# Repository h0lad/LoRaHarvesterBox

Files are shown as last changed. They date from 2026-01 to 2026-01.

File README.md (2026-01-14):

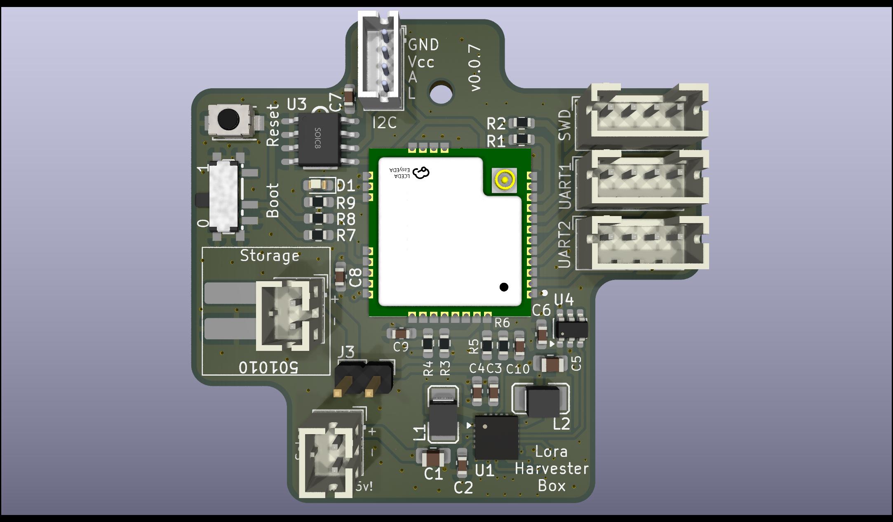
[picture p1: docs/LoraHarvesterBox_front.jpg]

MeshtasticRouterNode

## What is this thing?

This generic LoRa base board is built around the ST STM32WLE5CC (RAK3172) and the TI BQ25570 energy harvester.

It is suitable for a wide range of applications, including:

- Meshtastic (router, sensor) or Meshcore
- LoRaWAN sensors
- Generic raw LoRa devices
- Or virtually any other custom project (ham balloon? Transmitter for tracking penguins?) that utilizes the modulation schemes (FSK, GFSK, MSK, GMSK) of the SX1262

For persistent data storage, an optional FRAM IC (Infineon FM24V10) can be added using I²C. A variety of sensors can additonaly integrated through I²C, SPI (on the back), or USART interfaces.

The power supply design is highly flexible: alongside standard JST-PH connectors, the board also supports very small LiPo batteries (commonly used in in-ear headphones or Bluetooth headsets), which can be soldered directly. Such batteries are readily available on AliExpress (e.g. 501010). The TI BQ25570 also supports exotic storages like Supercaps, LTO, etc.

## Features

### Energy

- Capable of handling a huge variety of energy storages: LiPo, LiFePo4, LTO, SIB, Supercap
- Starts boosting at 600mV. Maximum input voltage is 5.5V. 
- Up to 110mA can be used from the application
- MPPT
- Optional load-switch to switch on/off the entire STM32/LoRa-modem based on the VBAT_OK signal

### Microcontroller

Uses the standardized RAK housing which can house a variety of platforms (ESP32, STM32, etc.) with compatible pins. This variant uses the RAK3172  (ST STM32WLE5CC: 256Kb Flash, 64Kb RAM, 48MHz).

Exposed interfaces:

- 2x USART
- 1x I2C
- 1x SPI (back)
- 2x ADC connected to energy source (like solar) and and energy storage (like LiPos) using voltage dividers
- Multiple break-out pins for GPIOs on the back

### LoRa

Uses the Semtech SX1262 integrated within the STM32 housing. Multiple RAK variants available for 433/470/868/915MHz.

### Data Storage

Infineon FM24V10: 1-MBit non-volatile F-RAM for storing firmware updates, messages or mesurement data

## Physical Dimensions

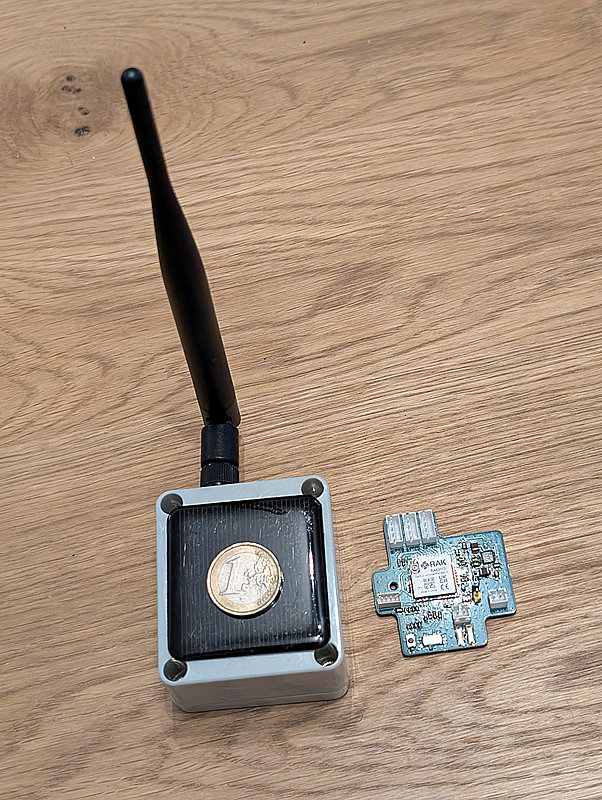
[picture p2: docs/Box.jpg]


This weirdo PCB format is designed around the cheapest water protected box from Aliexpress.

[Aliexpress, F-type, 63x58x35](https://de.aliexpress.com/item/1005005480970197.html)

## Design Decisions

### Why did you use the TI BQ25570?

It's the only energy harvester that supports up to 110mA peak current.

I'm not overly happy with this IC as it lacks a few useful features:

 - No I²C interface and ADC for reading voltages/currents

 - No Thermistor for switching off charging above and below specific temperatures

 - Doesn't switch off VOUT if the battery hits the lower threshold. It only signals it using a pin.

 - Rather annoying pin configuration. Layouting it doesn't make much fun.

 - It doesn't have interal high-precision resistors for configuring the voltage limits (VBAT_OV, etc.). Even with 1% tolerance resistors the resulting voltage ranges are barely acceptable due to error propagation.

 - Lowest possible battery voltage is 1.9V. This means we cannot utilize the full capacity of "exotic" storage types like LTO- and NaIon-cells.

Honestly - It's an old thing compared to the latest generation from ST or e-peas.
  
### Why not buying a "naked" ST STM32WLE5? 

Using a SoC module from RAK brings all the HF and impedancy matching. 

Everything else leaving the housing is not really critical signal wise.

Also it's not too expensive with 6€.

## Hardware

### Pin Configuration

MeshtasticRouterNode

#### ADC

| Signal | Pin | ADC Channel | Info | 
|:---:|:----:|:---:|:---:|
| Energy Storage Voltage | PB3 | A0 | Voltage goes through a Voltage Divider |
| Energy Source Voltage  | PB4 | A1 | Voltage goes through a Voltage Divider |

#### USART

| Peripheral | TX Pin | RX Pin |
|:---|:---|:---|
| UART1 | PB6 | PB7 |
| UART2 | PA2 | PA3 |

#### SWD

| Signal | Pin |
|:---|:----|
| SWDIO | PA13 |
| SWCLK | PA14 |

##### SPI

| Signal | Pin |
|:---|:----|
| SPI1, MOSI | PA7 |
| SPI1, MISO | PA6 |
| SPI1, CLK  | PA5 |
| SPI1, NSS  | PA4 |

#### LED

| Signal | Pin |
|:---|:----|
| LED | PA8 |

#### MISC

| Signal | Pin |
|:---|:----|
| VBAT_OK from TI BQ25570| PA15 |

### Resistors Values

**Warning:** 

You have to be super careful here. Don't trust your 1%-SMD-Resistor book from Aliexpress or Amazon. Measure each resistor with a high-resolution multimeter and then calculate the voltages according to the readings! A shabby Libreoffice Calc sheet can be found within the `docs` folder to do this.

I wrote a script for calculating resistor values here: [ti-bq25570-calculator](https://github.com/h0lad/ti-bq25570-calculator).

## Hardware Verification

### PCB Version v0.0.5

LoRaHarvesterBox PCB v0.0.5

**Power Chain**

✅ 3.3V from TI BQ25570

✅ Charges power storage as defined with R_OV1 and R_OV2

✅ VBAT_OK signal with 3.3V LiPo attached as a storage

✅ Boosts 0.6V to 3.3V without energy storage attached

✅ Lower and upper  VBAT_OK threshold

✅ Power switch (TI TPS22917DBV)

**ST STM32WL55**

✅ Connect to the SWD interface using a ST-Link

**Findings**

1. The BQ25570 doesn't like my extremely noisy power supply as a storage emulation. It doesn't come up.

2. You have to be very careful as even the tolerance of 1% resistors (R_OV1 and R_OV2) might cause overcharging. So stay away from the hard limits of your battery.

## License

CERN Open Hardware Licence Version 2 - Strongly Reciprocal

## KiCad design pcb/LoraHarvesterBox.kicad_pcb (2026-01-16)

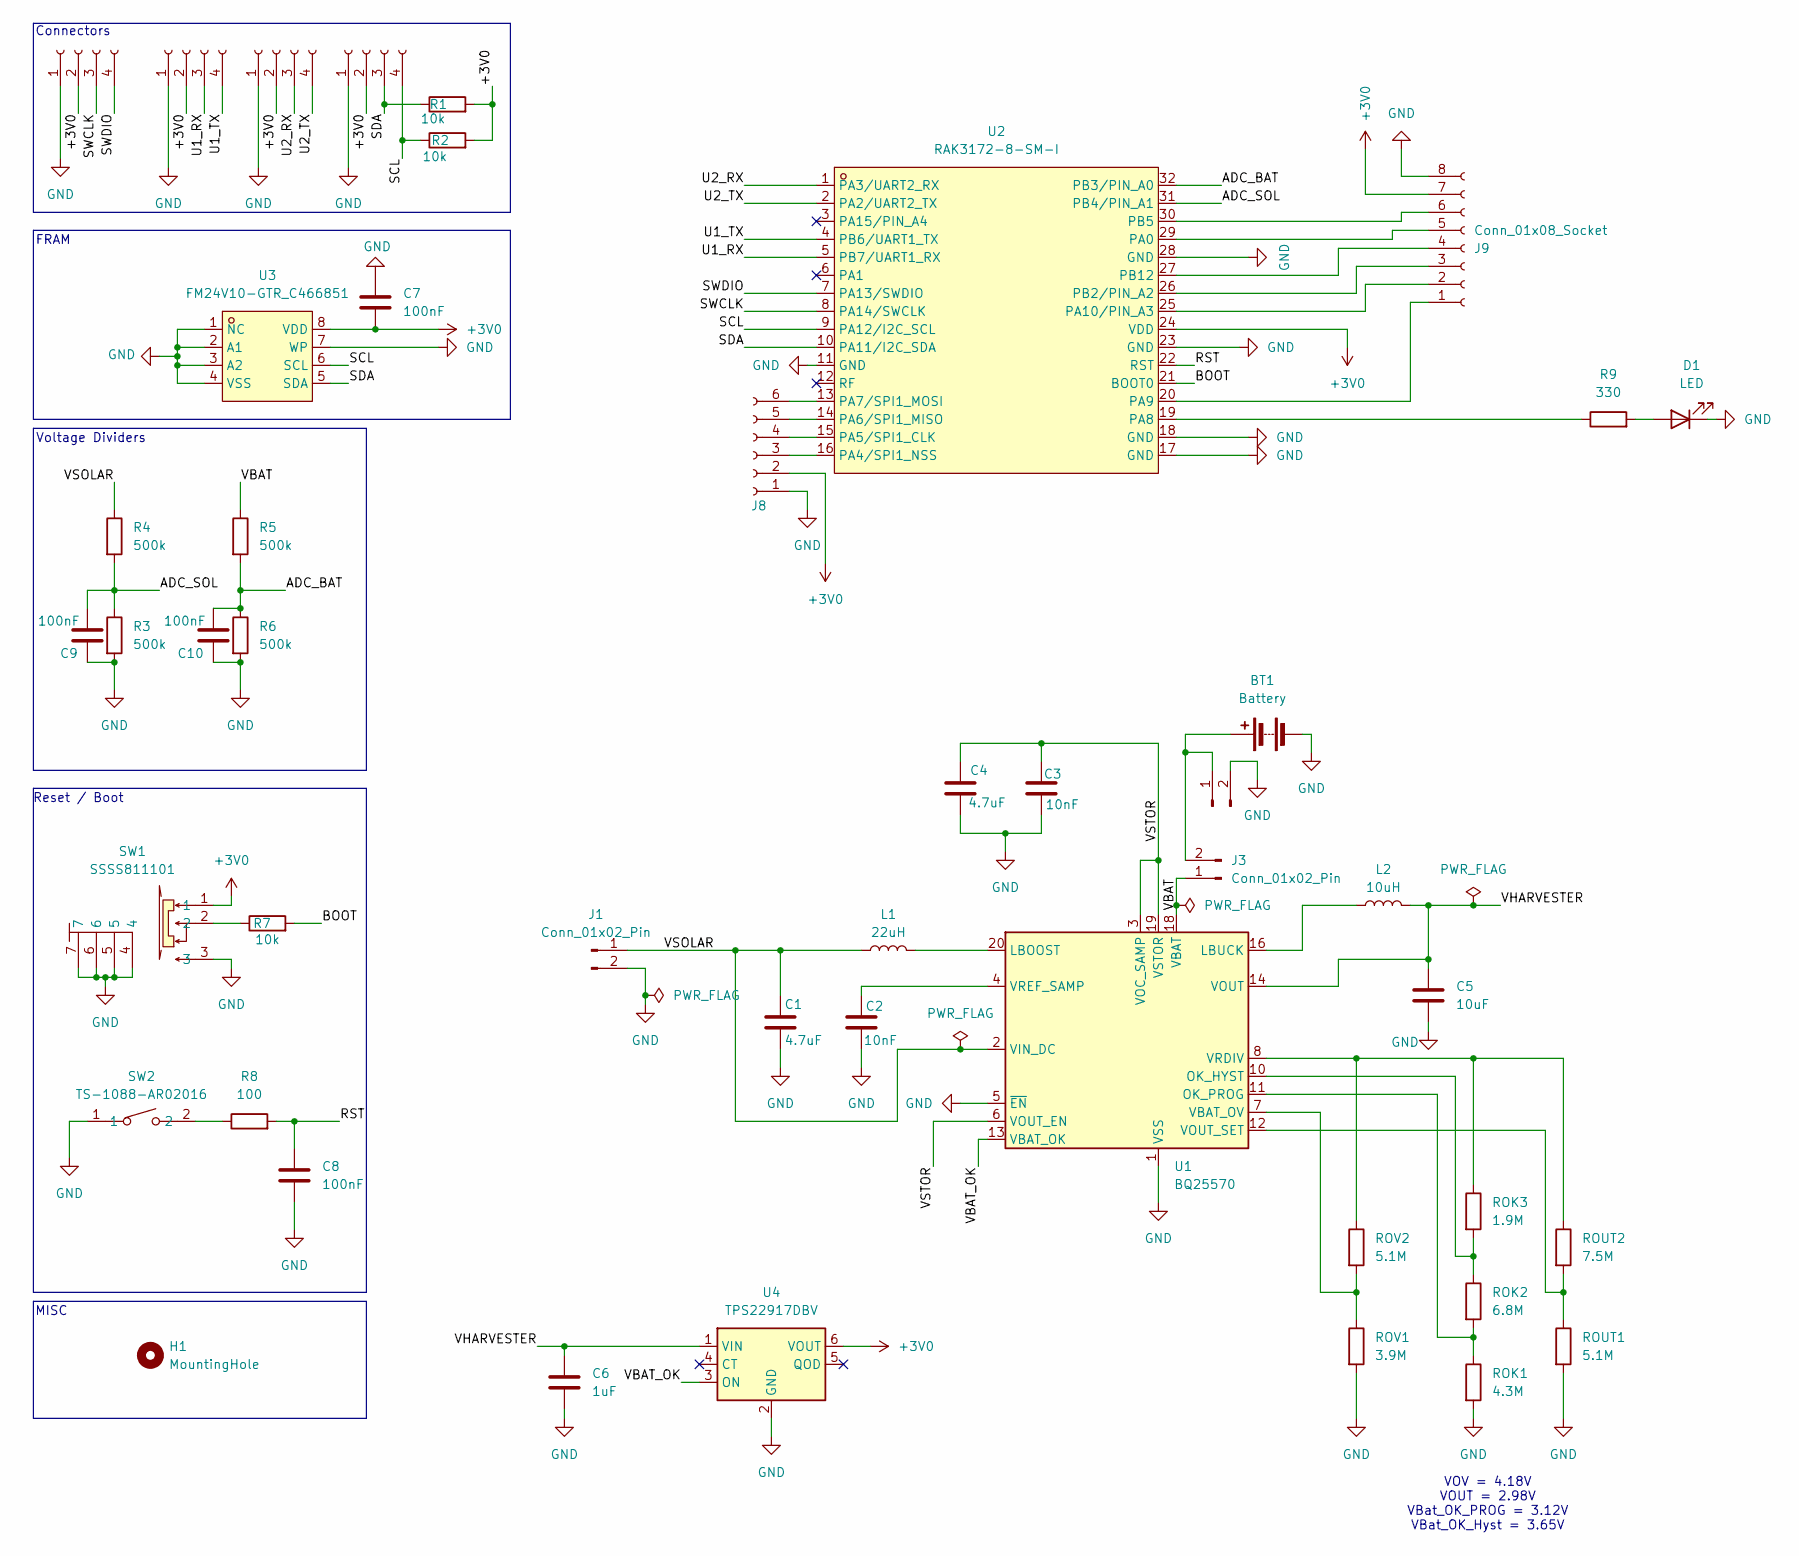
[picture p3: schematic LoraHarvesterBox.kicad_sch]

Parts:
BT1: Battery; 501010
C1: 4.7uF; C_0805_2012Metric_Pad1.18x1.45mm_HandSolder
C2, C3: 10nF; C_0603_1608Metric_Pad1.08x0.95mm_HandSolder
C4: 4.7uF; C_0603_1608Metric_Pad1.08x0.95mm_HandSolder
C5: 10uF; C_0805_2012Metric_Pad1.18x1.45mm_HandSolder
C6: 1uF; C_0603_1608Metric_Pad1.08x0.95mm_HandSolder
C7, C8, C9, C10: 100nF; C_0603_1608Metric_Pad1.08x0.95mm_HandSolder
D1: LED; LED_0603_1608Metric_Pad1.05x0.95mm_HandSolder
H1: MountingHole; MountingHole_2.2mm_M2
J1, J2: Conn_01x02_Pin; JST_PH_B2B-PH-K_1x02_P2.00mm_Vertical
J3: Conn_01x02_Pin; PinHeader_1x02_P2.54mm_Vertical
J4, J5, J6: Conn_01x04_Socket; JST_PH_B4B-PH-K_1x04_P2.00mm_Vertical
J7: Conn_01x04_Socket; JST_ZH_B4B-ZR_1x04_P1.50mm_Vertical
J8: Conn_01x06_Socket; PinHeader_1x06_P1.00mm_Vertical_SMD_Pin1Left
J9: Conn_01x08_Socket; PinHeader_1x08_P1.00mm_Vertical_SMD_Pin1Left
L1: 22uH; L1210
L2: 10uH; L1210
R1, R2: 10k; R_0603_1608Metric
R3, R4, R5, R6: 500k; R_0603_1608Metric_Pad0.98x0.95mm_HandSolder
R7: 10k; R_0603_1608Metric_Pad0.98x0.95mm_HandSolder
R8: 100; R_0603_1608Metric_Pad0.98x0.95mm_HandSolder
R9: 330; R_0603_1608Metric_Pad0.98x0.95mm_HandSolder
ROK1: 4.3M; R_0603_1608Metric_Pad0.98x0.95mm_HandSolder
ROK2: 6.8M; R_0603_1608Metric_Pad0.98x0.95mm_HandSolder
ROK3: 1.9M; R_0603_1608Metric_Pad0.98x0.95mm_HandSolder
ROUT1: 5.1M; R_0603_1608Metric_Pad0.98x0.95mm_HandSolder
ROUT2: 7.5M; R_0603_1608Metric_Pad0.98x0.95mm_HandSolder
ROV1: 3.9M; R_0603_1608Metric_Pad0.98x0.95mm_HandSolder
ROV2: 5.1M; R_0603_1608Metric_Pad0.98x0.95mm_HandSolder
SW1: SSSS811101; SW-SMD_SSSS811101; LCSC Part C109335
SW2: TS-1088-AR02016; SW-SMD_L3.9-W3.0-P4.45; LCSC Part C720477
U1: BQ25570; QFN-20-1EP_3.5x3.5mm_P0.5mm_EP2x2mm
U2: RAK3172-8-SM-I; WIRELM-SMD_32P-L15.5-W15.0-P1.00; LCSC Part C19723904
U3: FM24V10-GTR_C466851; SOIC-8_L5.0-W4.0-P1.27-LS6.0-BL; LCSC Part C466851
U4: TPS22917DBV; SOT-23-6

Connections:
+3V0: C7.2, J4.2, J5.2, J6.2, J7.2, J8.2, J9.7, R1.2, R2.2, SW1.1, U2.24 (VDD), U3.8 (VDD), U4.6 (VOUT)
/ADC_BAT: C10.2, R5.2, R6.1, U2.32 (PB3/PIN_A0)
/ADC_SOL: C9.2, R3.1, R4.2, U2.31 (PB4/PIN_A1)
/BOOT: R7.2, U2.21 (BOOT0)
/RST: C8.1, R8.2, U2.22 (RST)
/SCL: J7.4, R2.1, U2.9 (PA12/I2C_SCL), U3.6 (SCL)
/SDA: J7.3, R1.1, U2.10 (PA11/I2C_SDA), U3.5 (SDA)
/SWCLK: J4.3, U2.8 (PA14/SWCLK)
/SWDIO: J4.4, U2.7 (PA13/SWDIO)
/U1_RX: J5.3, U2.5 (PB7/UART1_RX)
/U1_TX: J5.4, U2.4 (PB6/UART1_TX)
/U2_RX: J6.3, U2.1 (PA3/UART2_RX)
/U2_TX: J6.4, U2.2 (PA2/UART2_TX)
/VBAT: J3.1, R5.1, U1.18 (VBAT)
/VBAT_OK: U1.13 (VBAT_OK), U4.3 (ON)
/VHARVESTER: C5.2, C6.2, L2.2, U1.14 (VOUT), U4.1 (VIN)
/VSOLAR: C1.1, J1.1, L1.1, R4.1, U1.2 (VIN_DC)
/VSTOR: C3.1, C4.1, U1.3 (VOC_SAMP), U1.6 (VOUT_EN), U1.19 (VSTOR)
GND: BT1.2 (-), C1.2, C2.2, C3.2, C4.2, C5.1, C6.1, C7.1, C8.2, C9.1, C10.1, D1.1 (K), J1.2, J2.2, J4.1, J5.1, J6.1, J7.1, J8.1, J9.8, R3.2, R6.2, ROK1.2, ROUT1.2, ROV1.2, SW1.3, SW1.4, SW1.5, SW1.6, SW1.7, SW2.1, U1.1 (VSS), U1.5 (~EN), U1.9 (VSS), U1.15 (VSS), U1.17 (VSS), U1.21 (VSS), U2.11 (GND), U2.17 (GND), U2.18 (GND), U2.23 (GND), U2.28 (GND), U3.1 (NC), U3.2 (A1), U3.3 (A2), U3.4 (VSS), U3.7 (WP), U4.2 (GND)
unnamed: BT1.1 (+), J2.1, J3.2
unnamed: D1.2 (A), R9.2
unnamed: J8.3, U2.16 (PA4/SPI1_NSS)
unnamed: J8.4, U2.15 (PA5/SPI1_CLK)
unnamed: J8.5, U2.14 (PA6/SPI1_MISO)
unnamed: J8.6, U2.13 (PA7/SPI1_MOSI)
unnamed: J9.1, U2.20 (PA9)
unnamed: J9.2, U2.25 (PA10/PIN_A3)
unnamed: J9.3, U2.26 (PB2/PIN_A2)
unnamed: J9.4, U2.27 (PB12)
unnamed: J9.5, U2.29 (PA0)
unnamed: J9.6, U2.30 (PB5)
unnamed: R7.1, SW1.2
unnamed: R8.1, SW2.2
unnamed: L1.2, U1.20 (LBOOST)
unnamed: L2.1, U1.16 (LBUCK)
unnamed: ROK2.1, ROK3.2, U1.10 (OK_HYST)
unnamed: ROK1.1, ROK2.2, U1.11 (OK_PROG)
unnamed: ROV1.1, ROV2.2, U1.7 (VBAT_OV)
unnamed: ROUT1.1, ROUT2.2, U1.12 (VOUT_SET)
unnamed: ROK3.1, ROUT2.1, ROV2.1, U1.8 (VRDIV)
unnamed: C2.1, U1.4 (VREF_SAMP)
unnamed: R9.1, U2.19 (PA8)

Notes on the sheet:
MISC
Connectors
Reset / Boot
VOV = 4.18V VOUT = 2.98V VBat_OK_PROG = 3.12V VBat_OK_Hyst = 3.65V
Voltage Dividers
FRAM

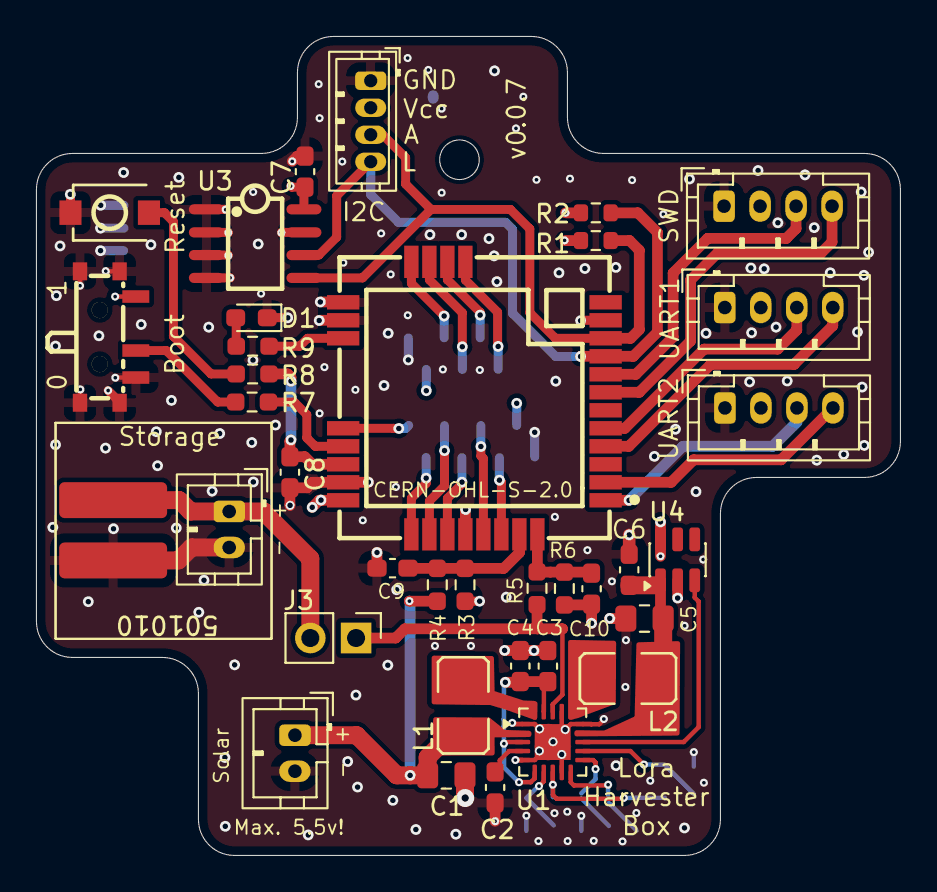
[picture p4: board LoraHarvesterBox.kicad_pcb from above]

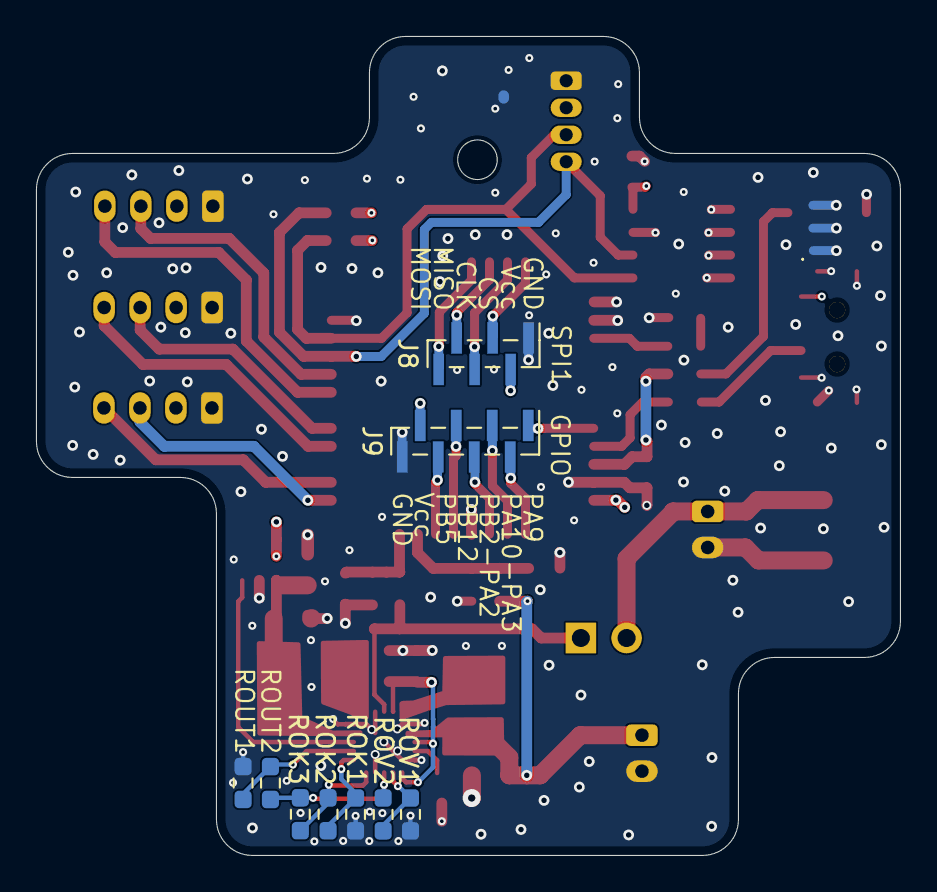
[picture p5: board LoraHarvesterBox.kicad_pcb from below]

Board: 4 copper layers, 48.0 x 45.5 mm, 46 parts (9 on the bottom side), 42 nets.

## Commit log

2025-11-23 README: add info regarding resistor tolerance impact on the voltages
2025-12-22 docs, pcb, sch: add missing buffer capacitor to power switch
    [LoraHarvesterBox.kicad_pcb, LoraHarvesterBox.kicad_sch]
2025-12-22 README: add information regarding lowest possible bat voltage
2026-01-16 pcb, sch: load switch now controls the entire 3.3V rail
    In the last version only the ST microcontroller was switched/on off by
    the load switch. This caused problems with the periphery: they stayed
    online with slowly fading into a brown out. This also fixes battery
    drain by half-dead sensors.
    [LoraHarvesterBox.kicad_pcb, LoraHarvesterBox.kicad_sch]
2026-01-16 pcb: clean up silk prints
    [LoraHarvesterBox.kicad_pcb]
2026-01-16 pcb: even more silk cleanups
    [LoraHarvesterBox.kicad_pcb]
2026-07-19 Clean up accidentally added production files
    [BOM-LoraHarvesterBox.csv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]

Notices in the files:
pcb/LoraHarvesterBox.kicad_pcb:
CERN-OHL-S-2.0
